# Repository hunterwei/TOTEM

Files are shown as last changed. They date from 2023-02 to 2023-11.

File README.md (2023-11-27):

<picture align="center">
  <source media="(prefers-color-scheme: dark)" srcset="/docs/images/TOTEM_logo_dark.svg">
  <source media="(prefers-color-scheme: light)" srcset="/docs/images/TOTEM_logo_bright.svg">
  TOTEM logo
</picture>

<h1 align="center">T O T E M</h1>

TOTEM is a 38 key column-staggered choc split keyboard. It is meant to be used with a SEEED XIAO BLE or RP2040.
It was created for the SEEED XIAO keyboard contest.\
[Here](https://www.hackster.io/geist/totem-a-tiny-splitkeyboard-with-splay-cb2e43) you can read about the process of making it.

***

## LAYOUT

TOTEM layout

***

## PCB

[Here](/PCB/) you can find the KiCad files and Gerbers for the TOTEM.

***

## CASE

You can use the TOTEM without a case, but [here](/case/) you can find one I made for it.

***

## BUILD GUIDE
  
The build guide for the TOTEM can be found [here](/docs/buildguide.md).

***

## FIRMWARE

[QMK config](https://github.com/GEIGEIGEIST/qmk-config-totem) for the TOTEM (wired using the XIAO RP2040)\
[ZMK config](https://github.com/GEIGEIGEIST/zmk-config-totem) for the TOTEM (wireless using the XIAO BLE)

***

## PHOTOS

This is the TOTEM in a black resin case

TOTEM black resin\
TOTEM black resin\
TOTEM black resin

***

## BUY 

You can buy TOTEM kits and finished builds on [keeb.supply](https://keeb.supply/products/geist-totem) (unfortunately Europe only for now)

***

## CREDITS

### INSPIRATION

I've added the additional pinky key to make the TOTEM compatible with the layout boards like the [Balbuzard](https://github.com/brow/balbuzard) by [Tom Brow](https://github.com/brow) and the [Osprette](https://github.com/smores56/osprette) by [Sam Mohr](https://github.com/smores56) use, where you put the keybinding of the top left and right keys on an outer pinky key.

### HELP FIXING THINGS

People who helped me create this board and fix stuff

#### PCB
- [Marco "Bob"](https://github.com/GroooveBob)

#### CASE
- [Freya](https://github.com/freya-irl)
- [Bubbleology](https://github.com/bubbleology)

#### FIRMWARE
- [Cem Aksoylar](https://github.com/caksoylar)
- [Grinnie](https://github.com/regicidalplutophage)
- [Alaa Saad Mansour](https://github.com/AlaaSaadAbdo)
- [pekudzu](https://github.com/pekudzu)

If you build a TOTEM I would be pretty happy to see some pictures. And if you want to leave me a tip you can do this [here](https://ko-fi.com/geigeigeist) (but please don't feel pressured)

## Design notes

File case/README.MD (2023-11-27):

# TOTEM CASE

Each half consists of a bottom and a top part (with an integrated switchplate) and is meant to be 3D printed in resin. 

I got good results from [JLCPCB](https://cart.jlcpcb.com/quote) (15€ + tax and shipping for a black or white version) and [PCBway](https://www.pcbway.com/rapid-prototyping/manufacture/?type=2&reffercode=TOP) (50€ + tax and shipping for a clear case).

Where possible use the STEP files, but the STL files should be fine too.

If you're sure you only will use the wired version you can also use the case without a power switch (USB) or use the case without a TRRS cutout if you plan on using the wireless version (BLE).

> **Note**
> The manufacturer will probably warn you about too thin sections, but it worked fine for me since these sections are pretty small.

TOTEM case

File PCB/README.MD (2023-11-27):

# TOTEM PCB FILES

## MANUFACTURING
If you want to get the PCB made you need to download the [ZIP](/PCB/totem_0-3/totem_0-3_gerbers.zip/) and upload it to the website of the manufacture 
I can recommend [JLCPCB](https://jlcpcb.com/), [Seeed Fusion](https://www.seeedstudio.com/fusion_pcb.html) or [PCBway](https://www.pcbway.com/).
If you want the silkscreen in yellow [AllPCB](https://www.allpcb.com/online_pcb_quote_new.html) is a pretty affordable choice.

- download [the ZIP file](/PCB/totem_0-3/totem_0-3_gerbers.zip/)
- upload the ZIP file to the website of the manufacturer.
- sometimes the Gerber preview from JLCPCB can't display the PCB, even when the files are fine. In this case use these dimensions: 258.7mm * 94.35mm
- PCB Thickness 1.6mm
- 2 layers
- PCB Qty as much as you like. One PCB is a full keyboard.
- PCB Color Black (or any other color you like)
- No impedance control
- Surface Finish HASL(with lead) if you want the easiest soldering experience or LeadFree HASL.
- Remove Order Number Yes

TOTEM PCB

***

## CHECK PINOUT OR TRACES

If you only want to check the traces or see what is connected to which pin you can take a look at these graphics.
You can also take a look at the [schematics](TOTEM_0-3_schematics.pdf) and the [PCB](TOTEM_0-3_PCB.pdf) as PDF.

TOTEM pinout

***

TOTEM traces

***

## TAKE A DEEPER LOOK OR MODIFY 

You can download the project if you need to take a deeper look or modify something. You need the Open Source software [KiCad](https://www.kicad.org/) to open it.

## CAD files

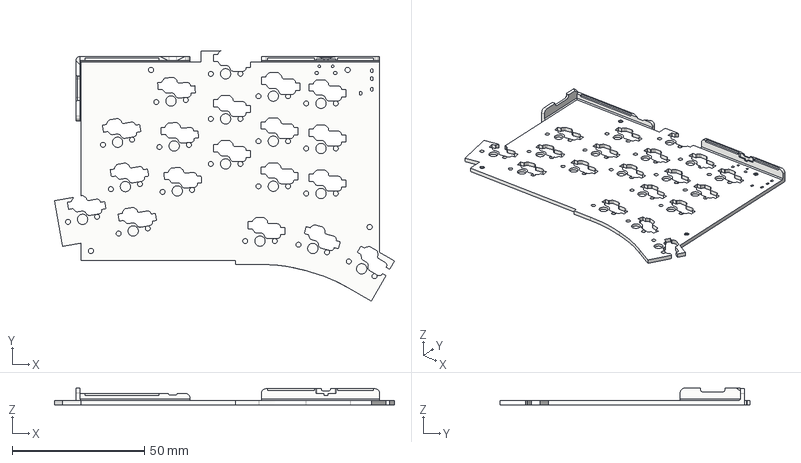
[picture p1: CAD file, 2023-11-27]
case/BLE/step/TOTEMcase_v08_6mm_BLE_Bottom_L.step
128.3 x 94.5 x 6.40 mm

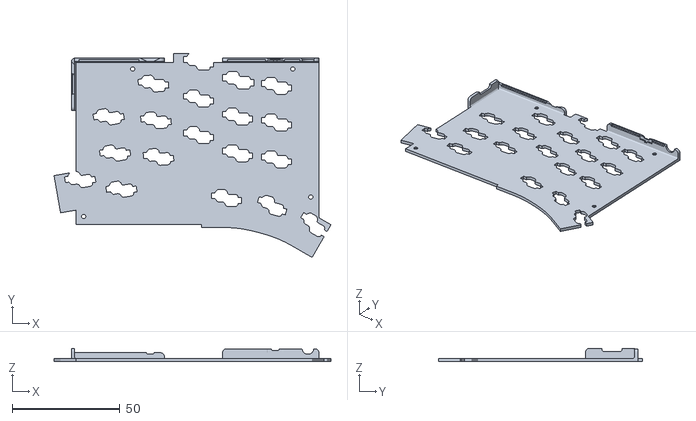
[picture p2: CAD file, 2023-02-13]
case/STL/TOTEM_case_v07_bottom_left.stl
128.3 x 94.5 x 6.20

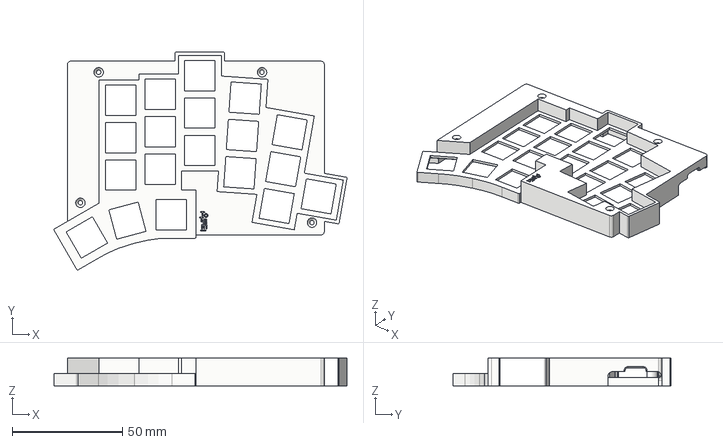
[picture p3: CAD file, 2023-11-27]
case/BLE/step/TOTEMcase_v08_6mm_BLE_Top_R.step
133.1 x 99.0 x 12.5 mm

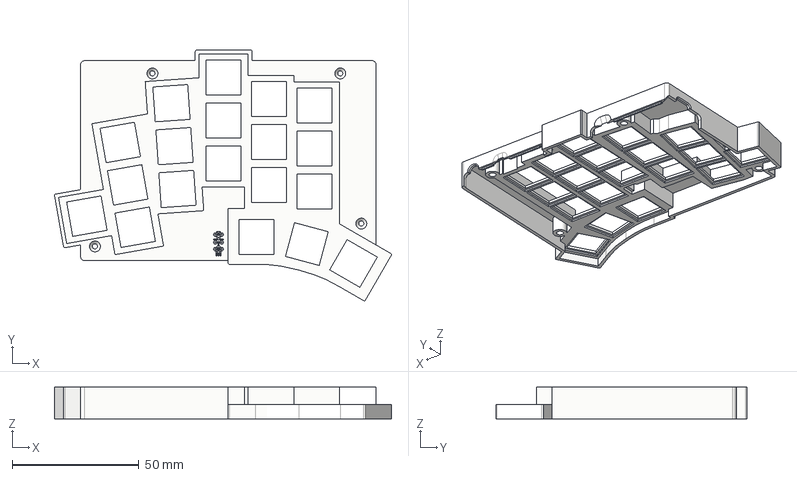
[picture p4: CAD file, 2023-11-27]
case/step/TOTEMcase_v08_6mm_Top_L.step
133.1 x 99.0 x 12.5 mm

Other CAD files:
case/step/TOTEMcase_v08_6mm_Bottom_L.step
case/USB/step/TOTEMcase_v08_6mm_USB_Bottom_L.step
case/USB/step/TOTEMcase_v08_6mm_USB_Bottom_R.step
case/BLE/step/TOTEMcase_v08_6mm_BLE_Bottom_R.step
case/step/TOTEMcase_v08_6mm_Top_R.step
case/USB/step/TOTEMcase_v08_6mm_USB_Top_L.step
case/BLE/step/TOTEMcase_v08_6mm_BLE_Top_L.step
case/step/TOTEMcase_v08_6mm_Bottom_R.step
case/USB/step/TOTEMcase_v08_6mm_USB_Top_R.step
case/BLE/stl/TOTEMcase_v08_6mm_BLE_Bottom_L.stl
case/BLE/stl/TOTEMcase_v08_6mm_BLE_Bottom_R.stl
case/BLE/stl/TOTEMcase_v08_6mm_BLE_Top_L.stl
case/BLE/stl/TOTEMcase_v08_6mm_BLE_Top_R.stl
case/USB/stl/TOTEMcase_v08_6mm_USB_Bottom_L.stl
case/USB/stl/TOTEMcase_v08_6mm_USB_Bottom_R.stl
case/USB/stl/TOTEMcase_v08_6mm_USB_Top_L.stl
case/USB/stl/TOTEMcase_v08_6mm_USB_Top_R.stl
case/stl/TOTEMcase_v08_6mm_Bottom_L.stl
case/stl/TOTEMcase_v08_6mm_Bottom_R.stl
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

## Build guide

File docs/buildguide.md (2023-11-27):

# TOTEM BUILD GUIDE

## PART LIST

### REQUIRED PARTS

| Part name | Count | Remarks | 
| :--- | :---: | :--- |
| TOTEM PCB | 01 | You can find the files for it [here](/PCB/) |
| Seeed XIAO | 02 | You can choose between the BLE version (wireless) or the RP2040 version (wired) |
| Choc key switch | 38 | Kailh Choc low profile key switches |
| diodes 1N4148W  | 38 | These are surface mount diodes in SOD123 package |
| 1u Choc keycaps | 38 | You can use the black or white keycaps from Kailh, but I recommend MBK, LDSA or CFX keycaps |
| reset button | 02 | Alps SKHLLCA010 |
| USB-C cable | 01 | For connecting the keyboard to your PC |
| power switch | 02 | MSK12C02 (only required for the Bluetooth build) |
| Lipo battery | 02 | There is space for a 15 x 22 x 7.5 mm battery (only required for the Bluetooth build) |
| TRRS jack | 02 | MJ-4PP-9 or PJ320A (only required for the wired build)|
| TRRS cable | 01 | Alternatively, you can use a TRS cable for [half-duplex](https://github.com/qmk/qmk_firmware/blob/master/docs/serial_driver.md#usart-half-duplex) (only required for the wired build)|

### OPTIONAL PARTS

| Part name | Count | Remarks | 
| :--- | :---: | :--- |
| switch socket | 38 | Switch sockets for Kailh choc switches |

### 3DP CASE PARTS

| Part name | Count | Remarks | 
| :--- | :---: | :--- |
| 3D printed case | 02 | Find the case files [here](/case) |
| 6mm M2 standoffs | 08 | 6mm round standoffs for screwing the top and bottom of the case together |
| 6mm M2 countersunk screws | 16 ||
| 8.5mm rubber feet | 8 | they can also be smaller |

## INTRODUCTION

Here is an overview of where and on which side each component needs to be soldered (click on the image to see a larger version).

TOTEM solder guide

***

## BREAK OFF HALVES

The PCB comes in one piece. You need to break it into two halves.

TOTEM PCB

After breaking them apart, you're left with some sprue marks, which you can remove with a file if you like, but you don't need to.

> **Warning**
> You should wear a mask while doing this since the FR4 dust is considered to be toxic.

PCB sprue marks

I paint the edges black using a sharpie, so they fit better with the top and bottom, but that's optional too.

PCB edges

***

## DIODES

The diodes need to be soldered on the top of the PCB. Pay attention to their orientation:  They have a small line on one side, which should be on the side the arrow on the PCB is facing to.

<p align="center">
<picture>
  <source media="(prefers-color-scheme: dark)" srcset="/docs/images/buildguide/diodes_dark.svg">
  <source media="(prefers-color-scheme: light)" srcset="/docs/images/buildguide/diodes_bright.svg">
  diode orientation
</picture>
</p>

Apply a small amount of solder on one pad.

Solder on one pad

Then use tweezers to place the diode on the pads and reheat the solder to secure the diode.

Solder diode

Now you can solder the second pad.

***
 
## SWITCH SOCKETS (optional)

Here you can apply the same technique as used for the diodes: Apply some solder on one of the pads first.

switch sockets pad

Then place the switch socket in the silk screen markings. The orientation matters here too. Especially if you plan on using the case.

<p align="center">
<picture>
  <source media="(prefers-color-scheme: dark)" srcset="/docs/images/buildguide/socket_dark.svg">
  <source media="(prefers-color-scheme: light)" srcset="/docs/images/buildguide/socket_bright.svg">
  hotswap socket orientation
</picture>
</p>

hotswap socket right and wrong orientation

Then reheat the solder. 
Apply some pressure with a pair of tweezers to make sure the socket is fully seated.\
Now solder the second pad.

switch socket soldered

***

## POWER SWITCHES (only required for Bluetooth build)

Apply a tiny bit of solder on the bigger, outer pads on top of the PCB. 

power switch pads

The power switch has some tiny knobs on its bottom, which fit into the PCB holes. Hold it in place with tweezers and then reheat the solder on the pad. After this, you can solder the other pad and the three pins.

power switch

***

## RESET SWITCHES

Insert the switch into the top of the PCB. 

reset switch

I placed the footprint a bit more towards the edge, than it's meant to be, to integrate it better into the case. Therefore the tiny stabilizer on the bottom of the switch doesn't touch the PCB anymore. Make sure it is aligned with the PCB vertically, so it's oriented correctly.

reset switch orientation

Then solder the four pins on the bottom to the PCB

reset switch solder

***

## TRRS JACKS (optional)

> **Warning**
> You don't need the TRRS jacks for running the TOTEM with ZMK. Actually, you can damage your board when connecting it through TRRS, while also connected to a battery.

Install the TRRS jack on the bottom side of the PCB. The place where you should insert it is marked with a white line.

TRRS jack

You may want to use some masking tape to hold it in place since you need to solder it on the bottom.

TRRS jack taped

Then solder the pins on the bottom to the PCB.

TRRS jack soldered

***

## MICROCONTROLLER

> **Warning**
> First flash the microcontroller to make sure it works, before soldering it in. Especially since you can't use sockets.

Place the microcontroller in its place. 

> **Note**
> If you're struggling with keeping it in place you can use the headers, which came with it, and some double-sided tape. But make sure it sits flat on the PCB. Otherwise, the case won't fit.

Apply some flux and try to hold the iron at an angle where you touch the pads of the microcontroller and the PCB while adding solder.

soldering MCU

The pads on the back are a bit fiddly to solder, so you should add a lot of flux to the pads on the microcontroller first. Then apply the same technique as on the front: Try to touch the pads on the microcontroller and the PCB before adding solder. 

soldering MCU back

***

## BATTERY (optional)

> **Warning**
> You don't need the battery for running the TOTEM with QMK. Actually, you can damage your board when connecting it through TRRS, while also connected to a battery.

You probably need to shorten the cables and tin them, since the length needs to be pretty short, to fit. I've also plasti dipped mine.

shorten battery cables

> **Warning**
> Before attaching the battery in any way to the PCB set the power switch to off (right on both sides).

You can see which cable needs to go in which eye by the silkscreen below the eyes. Red is + / Black is -.

battery face

Attach the wires of the battery to the pads and solder them in.

Ouch

***

## CLEANING

You can use an old toothbrush and some isopropanol to clean it from residues. 

***

## FIRMWARE

If you have not already flashed the firmware to the microcontroller you should do it now.\
[Here](https://github.com/GEIGEIGEIST/zmk-config-totem) you can find the ZMK firmware for the TOTEM.\
[Here](https://github.com/GEIGEIGEIST/qmk-config-totem) you can find the QMK firmware for the TOTEM.\

Probably a good idea to also install switches to make sure all of them work, before inserting the board into the case.

PCB with switches

***

## CASE

> **Note**
> I'm using the transparent version of the case, so it's easier to see where everything goes, but it's identical to the black/white case.

First, install the standoffs from below into the top of the case.

Top case with standoffs

Next screw them in from above.

Top case with screws

Now insert the board into the top and connect them using the switches.

Top case with switches

The bottom has some insets for using rubber feet. 

bottom case insets

You can then attach the bottom to the case and screw it in. 

bottom case screws

***

## FINAL BUILD

This is what the final keyboard will probably look like. 

final build
